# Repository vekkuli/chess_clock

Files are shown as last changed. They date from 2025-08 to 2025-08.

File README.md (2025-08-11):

# Chess Clock :clock1:

Clip

This repo contains design and fabrication files for my DIY chess clock project. The main components in the design are

    Two 4-digit red 7-segment displays
    MAX7219 display driver
    Pro Micro microcontroller board
    3D printed enclosure and other parts
    5 V power supply (e.g. PowerBoost 500C and LiPoly battery)
    Cut-to-shape acrylic window and tint film

## PCB

The KiCad project can be found in [chess_clock_pcb](chess_clock_pcb) folder. The [fabrication files](chess_clock_pcb/fabrication) are also included and can be used to order the PCBs directly. The fabrication files were produced according to JLCPCB requirements. Black solder mask is recommended.

All the components are through-hole. Happy soldering! Just don't make the same mistake I did the first time and forget which side each component is supposed to be on :grin:. See the correct placement here:

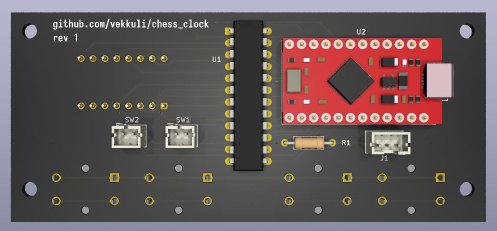
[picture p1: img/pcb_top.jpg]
PCB Top
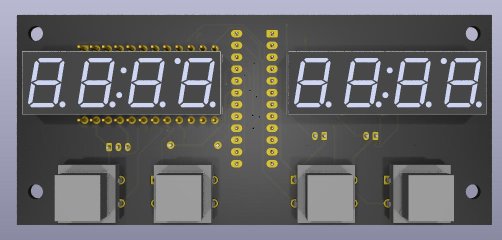
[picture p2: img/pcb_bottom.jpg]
PCB Bottom
 

*Note that the SW2 JST connector is not actually required. I put it there just in case but the current FW does not use it.*

## 3D printed parts

I used black PLA and white PETG. The main body was printed the display/button side facing down and using organic supports (PrusaSlicer). The following mesh files can be found in the [3d_print folder](3d_print):

    3d_print/bottom.3mf
    3d_print/bushing.3mf
    3d_print/button_type1.3mf
    3d_print/button_type1_fill.3mf
    3d_print/button_type2.3mf
    3d_print/button_type2_fill.3mf
    3d_print/main_body.3mf
    3d_print/rocking_switch.3mf

*Note that I actually used off-the-shelf plastic bushings that I just happened to have around, but I imagine 3D printed ones will work just as well.*

## Acrylic window

The acrylic window cut shape can be found in [3d_print/acrylic_cut.dxf](3d_print/acrylic_cut.dxf). 2 mm acrylic can be easily cut using for example a CO2 laser cutter.

The 5 % tint film (e.g. car window tint) is needed to get good contrast from the display.

## Bill of materials

Full (I hope) bill of materials below. Most parts can be sourced from DigiKey.

| Quantity  | Item | Info/part number/digikey |
|---|---|---|
| 2 | 4-digit CC 7-segment display  | TDCR1060M-ND |
| 1 | Display driver | MAX7219CNG-ND |
| 1 | USB-C port for 5 V input | 2057-USB-C20-S-VT-CS15-WP-BK-ND |
| 1 | 10k 1/4W resistor | Affects LED brightness |
| 1 | JST PH 2-pos connector | B2B-PH-K-S |
| 1 | JST PH 3-pos connector | B3B-PH-K-S |
| 1 | Arduino Pro Micro board | Microcontroller board |
| 4 | Tactile switches | SW414-ND |
| 1 | Omron limit switch | SS-5GL13 |
| 1 | PowerBoost 500C | 5V supply and LiPoly charger |
| 1 | LiPoly battery | e.g. 3.7 V/2500 mAh |
| 1 | M2.5 screws and nuts | |
| 1 | M3 screws and nuts | |
| 1 | M4x40 socket head screw | Cut to about 36 mm (or use M4x35) |
| 1 | M4 nyloc nut | |
| 1 | Acrylic window (2 mm) | Laser cut to shape |
| 1 | 5 % dark tint film | Greatly improves display contrast |
| 2 | (optional) O-ring | To soften the button press |

## Pro Micro brownout fix :exclamation:

I don't know how they managed to mess this up :angry: but Pro Micro has a design flaw that causes it to brown out when started by applying power directly via either USB or VCC pin, i.e., not using the regulator on the board. One way to fix this, and what I did, is to remove the regulator IC. While at it, I decided to remove the tantalum capacitors as well.

## Images

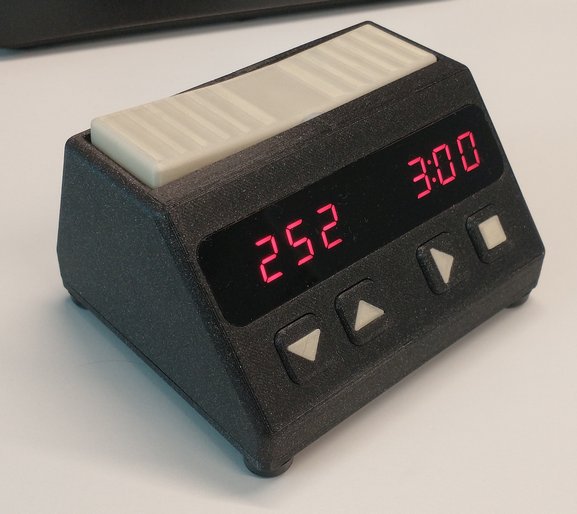
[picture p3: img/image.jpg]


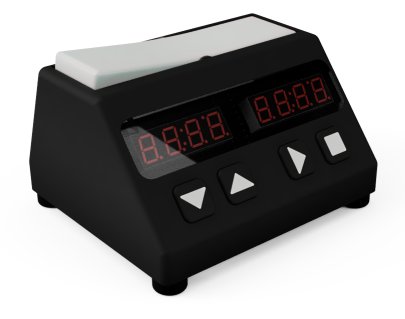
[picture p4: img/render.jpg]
Render


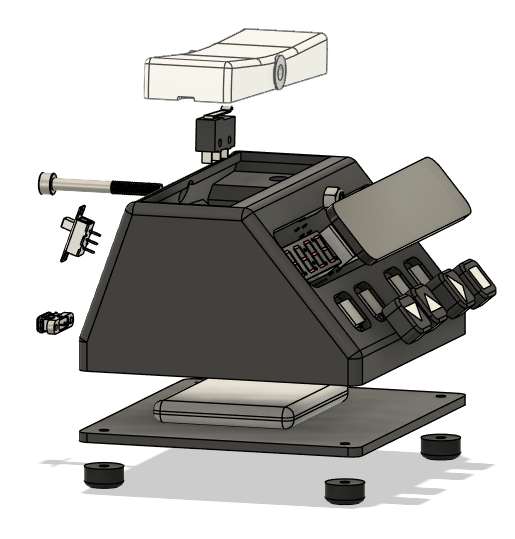
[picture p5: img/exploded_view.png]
Exploded View


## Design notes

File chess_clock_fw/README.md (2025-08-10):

# chess_clock firmware

The script.bat can be used to recover the Pro Micro bootloader in case of crashing program.

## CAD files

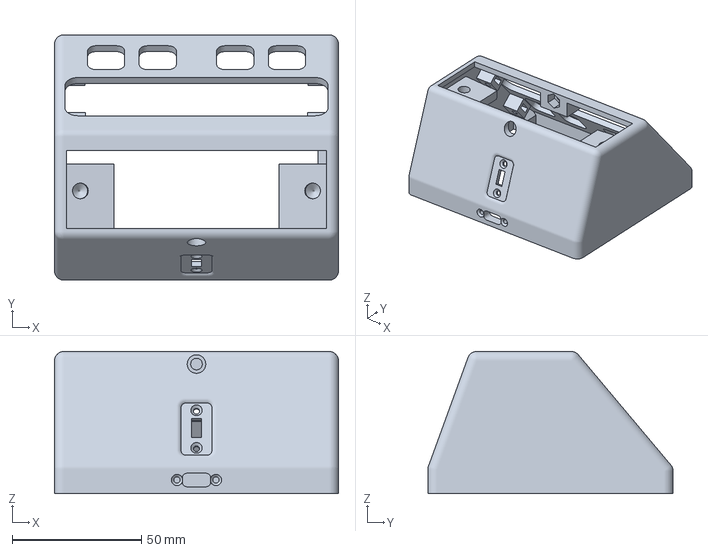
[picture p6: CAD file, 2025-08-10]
3d_print/main_body.3mf
110.0 x 95.0 x 55.0 mm

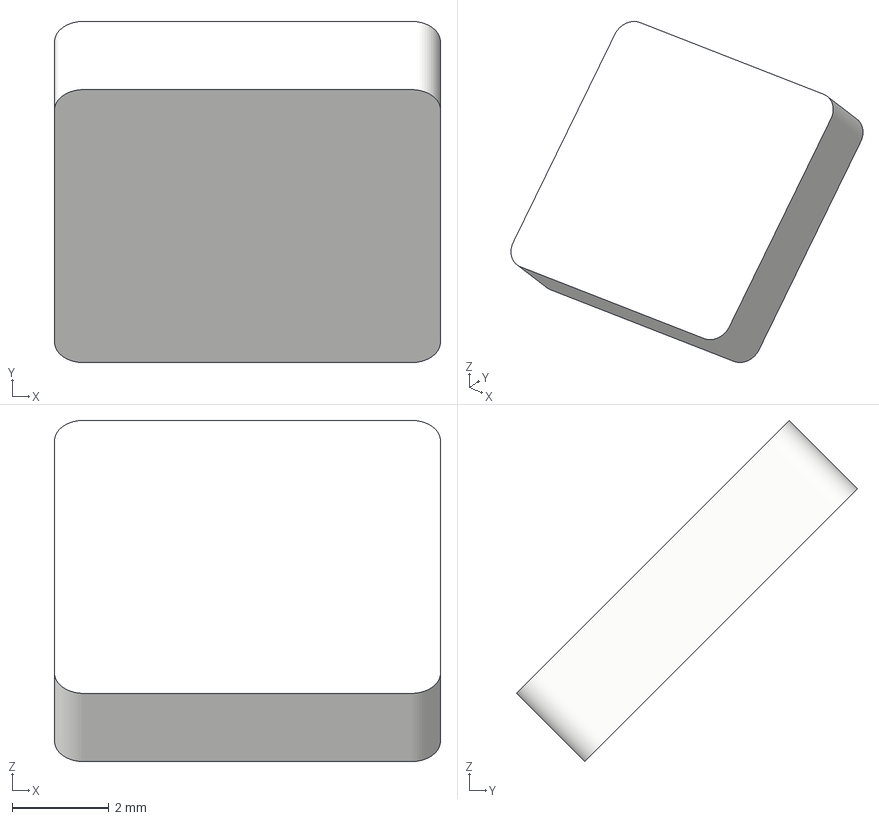
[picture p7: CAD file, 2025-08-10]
3d_print/button_type2_fill.3mf
8.00 x 7.07 x 7.07 mm

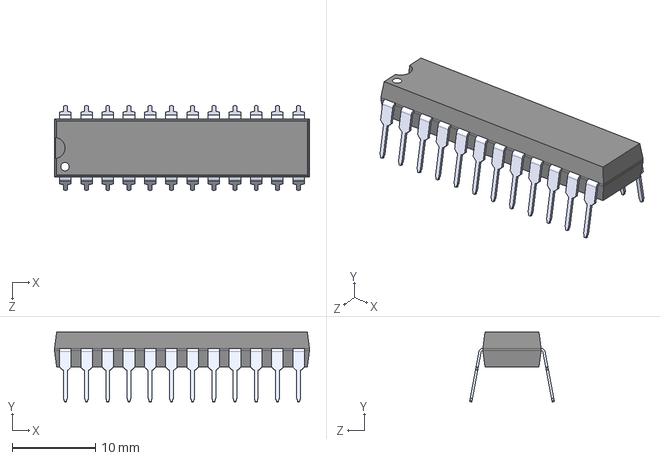
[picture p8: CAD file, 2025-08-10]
chess_clock_pcb/assets/MAX7219CNG.step
30.5 x 8.38 x 10.2 mm

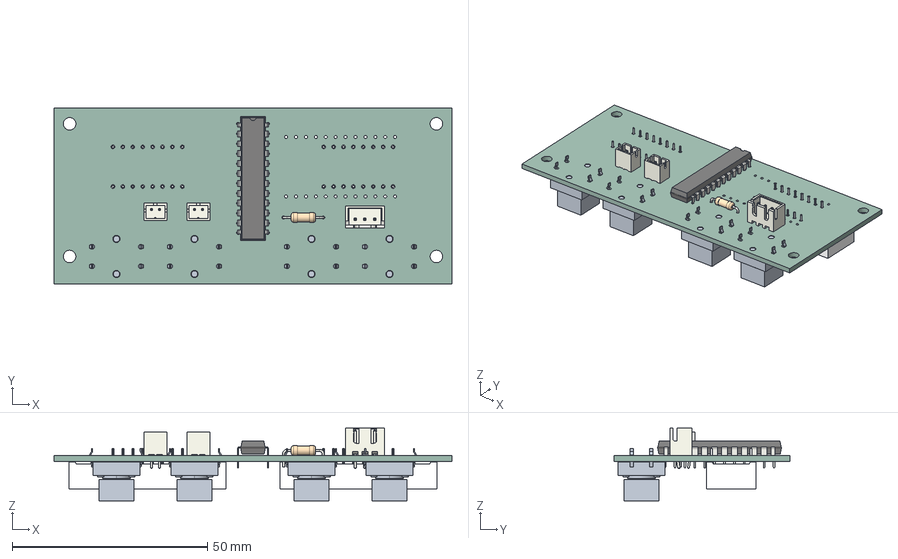
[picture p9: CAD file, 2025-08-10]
chess_clock_pcb/chess_clock_pcb.step
102.0 x 45.0 x 18.7 mm
R_Axial_DIN0207_L6.3mm_D2.5mm_P10.16mm_Horizontal
JST_PH_B2B-PH-K_1x02_P2.00mm_Vertical x 2
DIP-24_W7.62mm
JST_XH_B3B-XH-A_1x03_P2.50mm_Vertical
B3F_4050_BASE x 4
B32_1200 x 4
B3F_4050_BUTTON x 4
TDCR1060M x 2
chess_clock_pcb_PCB

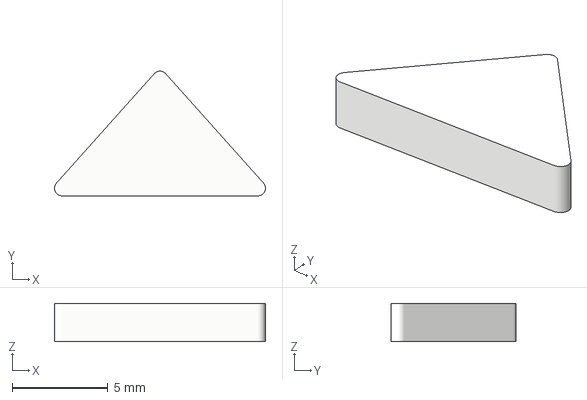
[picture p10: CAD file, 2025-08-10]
3d_print/button_type1_fill.3mf
11.0 x 6.51 x 2.00 mm

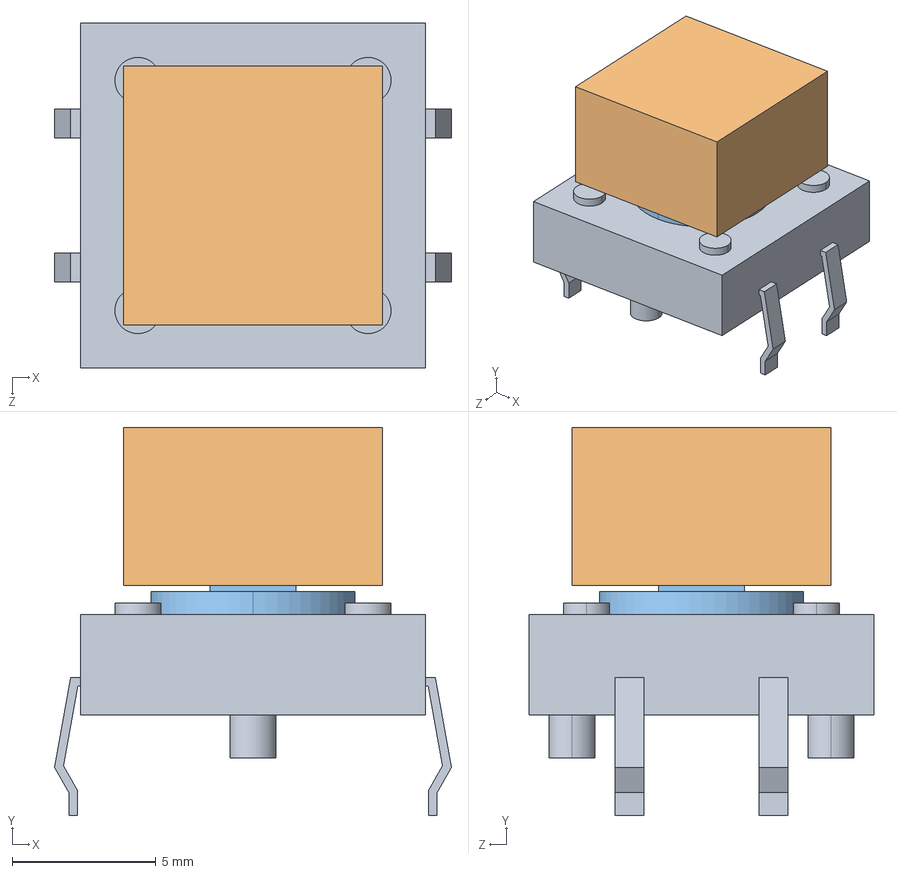
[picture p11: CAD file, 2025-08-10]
chess_clock_pcb/assets/B3F-4050.step
13.8 x 13.5 x 12.0 mm
B3F_4050_BASE
B32_1200
B3F_4050_BUTTON

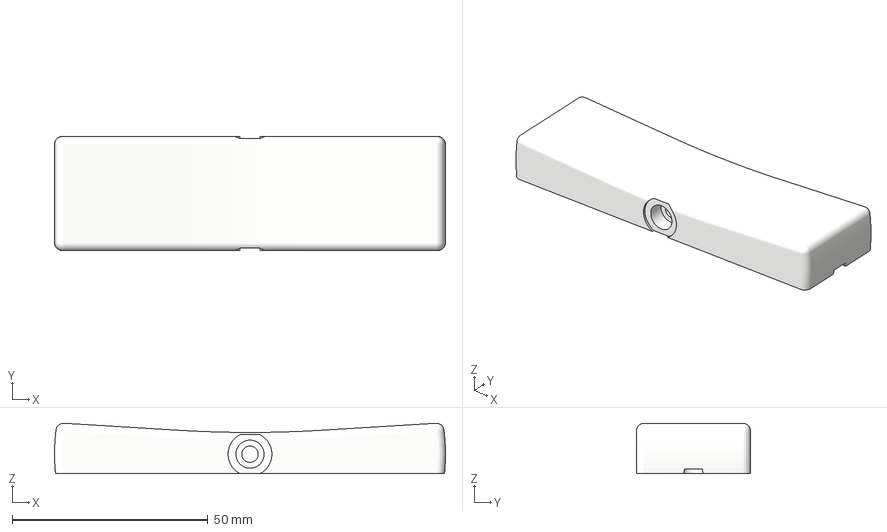
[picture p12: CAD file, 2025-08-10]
3d_print/rocking_switch.3mf
100.0 x 29.2 x 12.9 mm

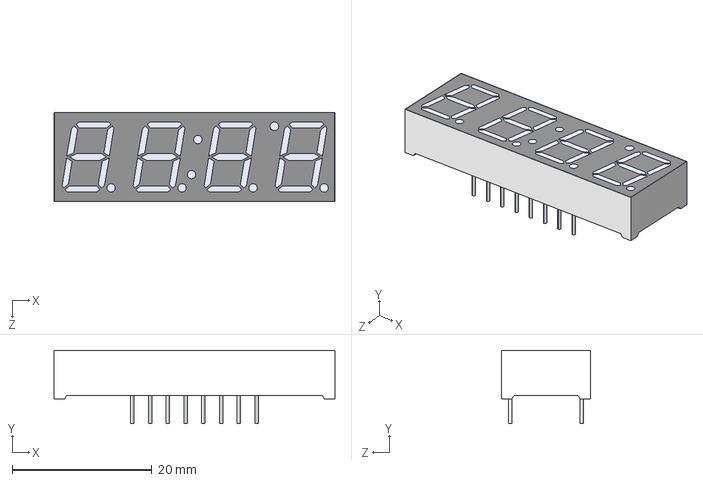
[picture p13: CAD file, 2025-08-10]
chess_clock_pcb/assets/TDCR1060M.step
40.2 x 10.5 x 12.8 mm

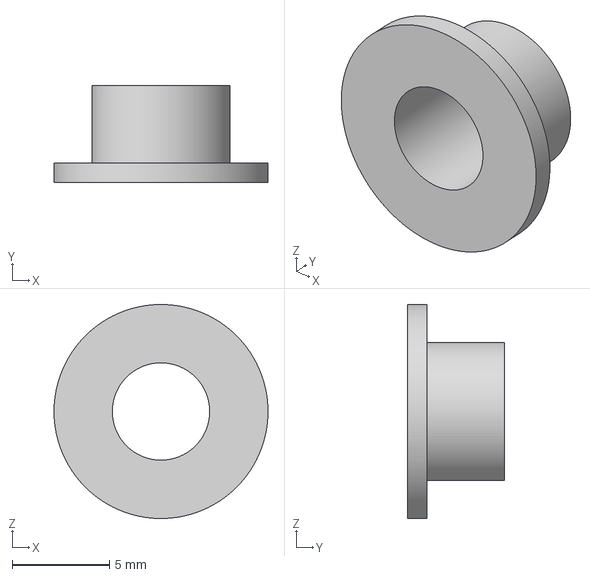
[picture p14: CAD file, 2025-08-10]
3d_print/bushing.3mf
11.0 x 5.00 x 11.0 mm

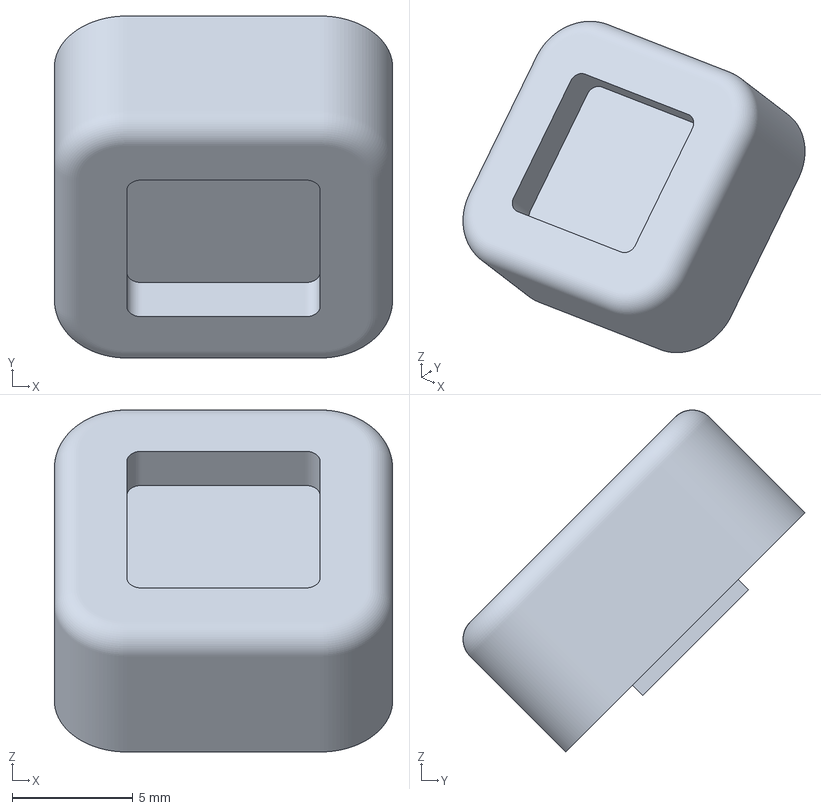
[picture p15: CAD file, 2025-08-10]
3d_print/button_type2.3mf
14.0 x 14.2 x 14.2 mm

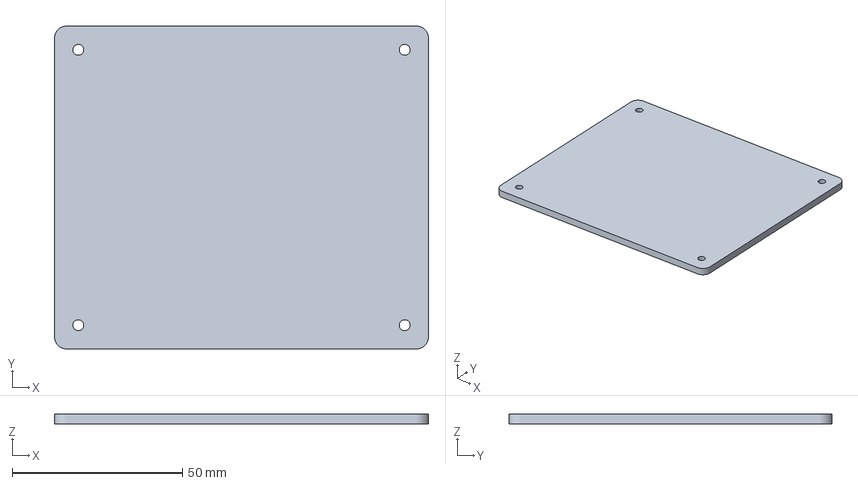
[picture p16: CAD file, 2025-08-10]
3d_print/bottom.3mf
110.0 x 95.0 x 3.00 mm

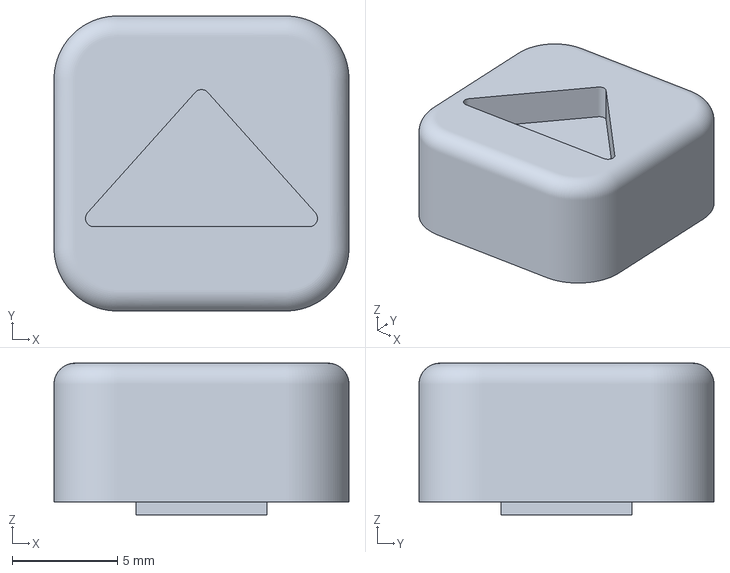
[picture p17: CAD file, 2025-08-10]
3d_print/button_type1.3mf
14.0 x 14.0 x 7.20 mm

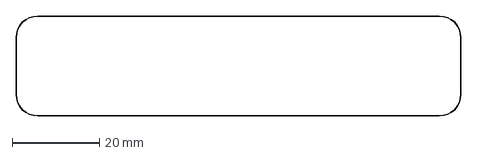
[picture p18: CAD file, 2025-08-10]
3d_print/acrylic_cut.dxf
101.8 x 22.8 mm

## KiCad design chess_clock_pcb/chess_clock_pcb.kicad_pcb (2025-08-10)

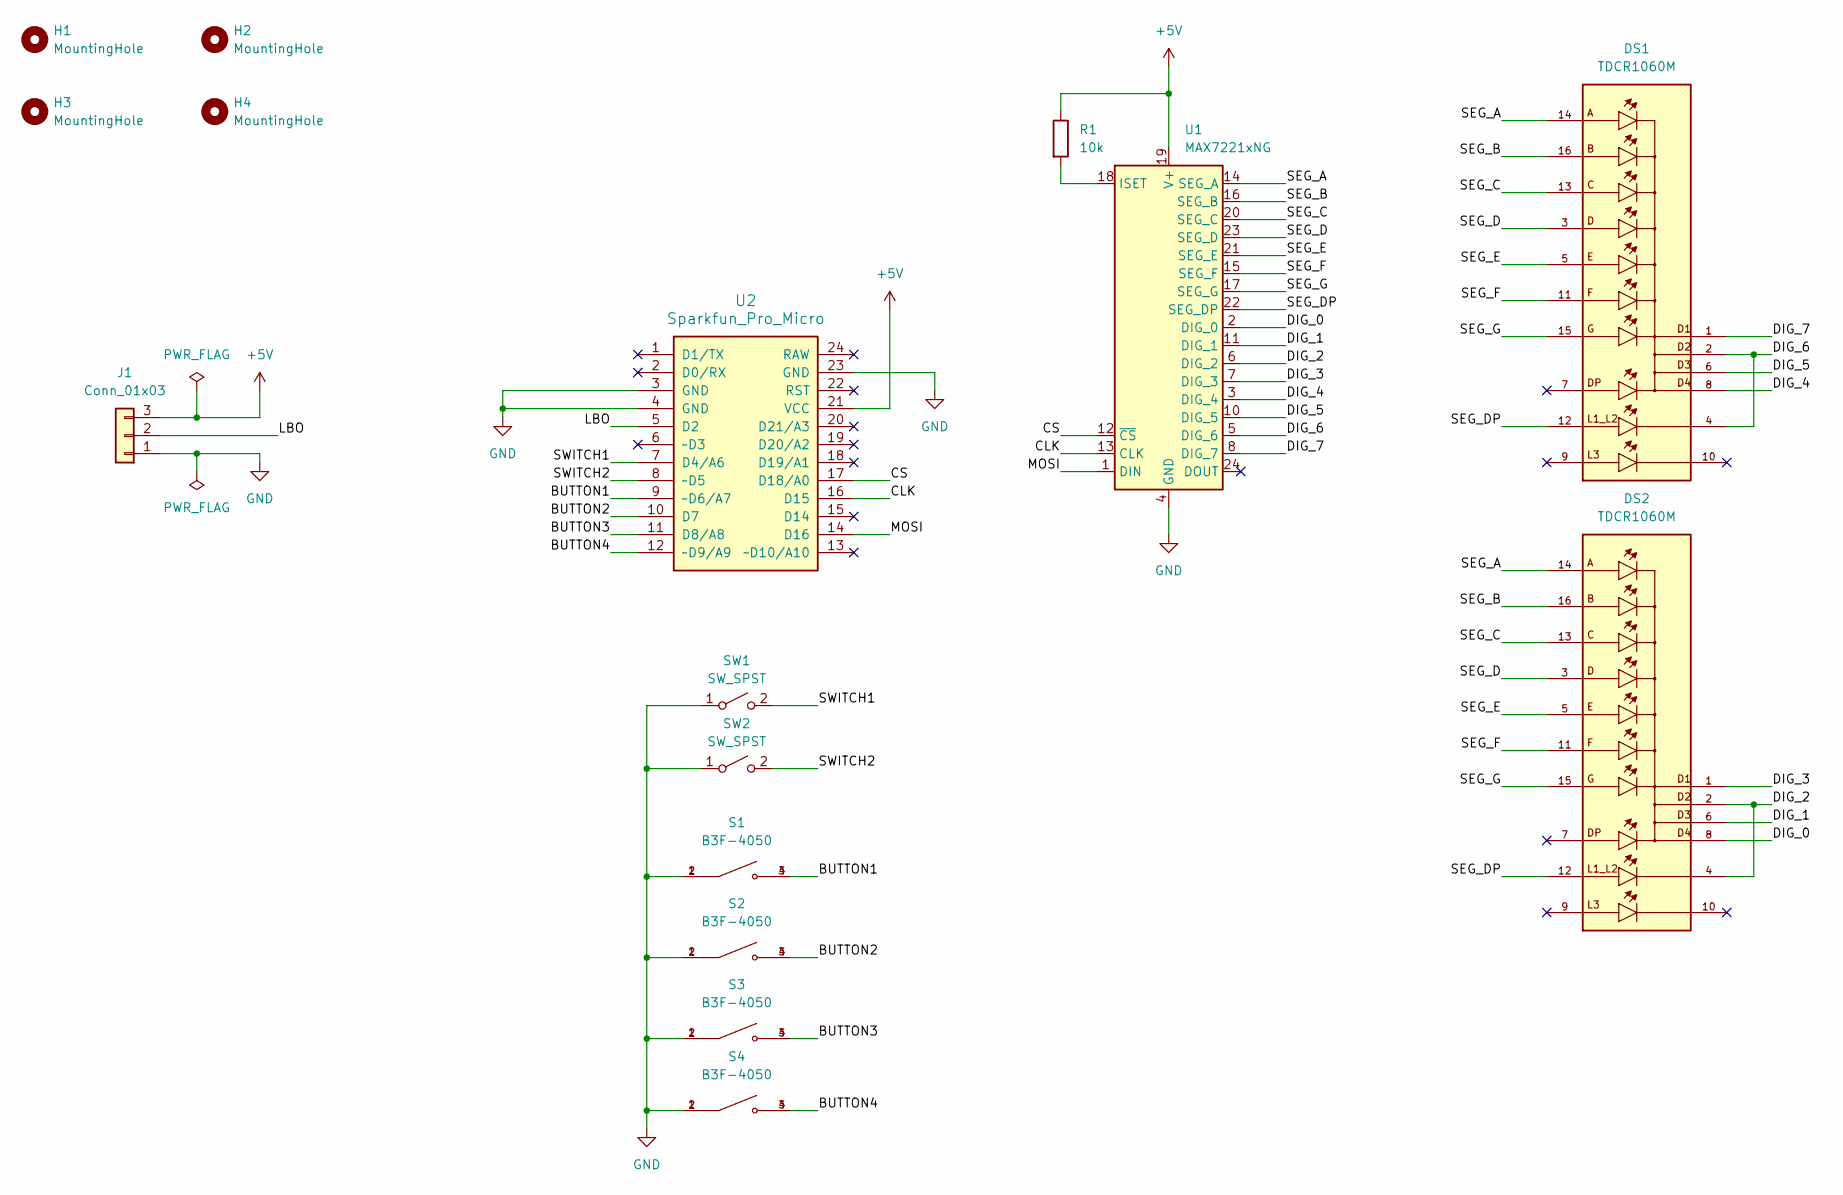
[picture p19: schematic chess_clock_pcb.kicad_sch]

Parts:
DS1, DS2: TDCR1060M; DISPLAY_TDCR1060M; PARTREV 1.7
H1, H2, H3, H4: MountingHole; MountingHole_3.2mm_M3
J1: Conn_01x03; JST_PH_B3B-PH-K_1x03_P2.00mm_Vertical
R1: 10k; R_Axial_DIN0207_L6.3mm_D2.5mm_P10.16mm_Horizontal
S1, S2, S3, S4: B3F-4050; SW_B3F-4050; Digi-Key_Part_Number SW414-ND
SW1, SW2: SW_SPST; JST_PH_B2B-PH-K_1x02_P2.00mm_Vertical
U1: MAX7221xNG; DIP-24_W7.62mm_LongPads
U2: Sparkfun_Pro_Micro

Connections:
+5V: J1.3, R1.1, U1.19 (V+), U2.21 (VCC)
/BUTTON1: S1.3, S1.4, U2.9 (~D6/A7)
/BUTTON2: S2.3, S2.4, U2.10 (D7)
/BUTTON3: S3.3, S3.4, U2.11 (D8/A8)
/BUTTON4: S4.3, S4.4, U2.12 (~D9/A9)
/CLK: U1.13 (CLK), U2.16 (D15)
/CS: U1.12 (~CS), U2.17 (D18/A0)
/DIG_0: DS2.8, U1.2 (DIG_0)
/DIG_1: DS2.6, U1.11 (DIG_1)
/DIG_2: DS2.2, DS2.4, U1.6 (DIG_2)
/DIG_3: DS2.1, U1.7 (DIG_3)
/DIG_4: DS1.8, U1.3 (DIG_4)
/DIG_5: DS1.6, U1.10 (DIG_5)
/DIG_6: DS1.2, DS1.4, U1.5 (DIG_6)
/DIG_7: DS1.1, U1.8 (DIG_7)
/LBO: J1.2, U2.5 (D2)
/MOSI: U1.1 (DIN), U2.14 (D16)
/SEG_A: DS1.14, DS2.14, U1.14 (SEG_A)
/SEG_B: DS1.16, DS2.16, U1.16 (SEG_B)
/SEG_C: DS1.13, DS2.13, U1.20 (SEG_C)
/SEG_D: DS1.3, DS2.3, U1.23 (SEG_D)
/SEG_DP: DS1.12, DS2.12, U1.22 (SEG_DP)
/SEG_E: DS1.5, DS2.5, U1.21 (SEG_E)
/SEG_F: DS1.11, DS2.11, U1.15 (SEG_F)
/SEG_G: DS1.15, DS2.15, U1.17 (SEG_G)
/SWITCH1: SW1.2 (B), U2.7 (D4/A6)
/SWITCH2: SW2.2 (B), U2.8 (~D5)
GND: J1.1, S1.1, S1.2, S2.1, S2.2, S3.1, S3.2, S4.1, S4.2, SW1.1 (A), SW2.1 (A), U1.4 (GND), U1.9 (GND), U2.3 (GND), U2.4 (GND), U2.23 (GND)
unnamed: R1.2, U1.18 (ISET)

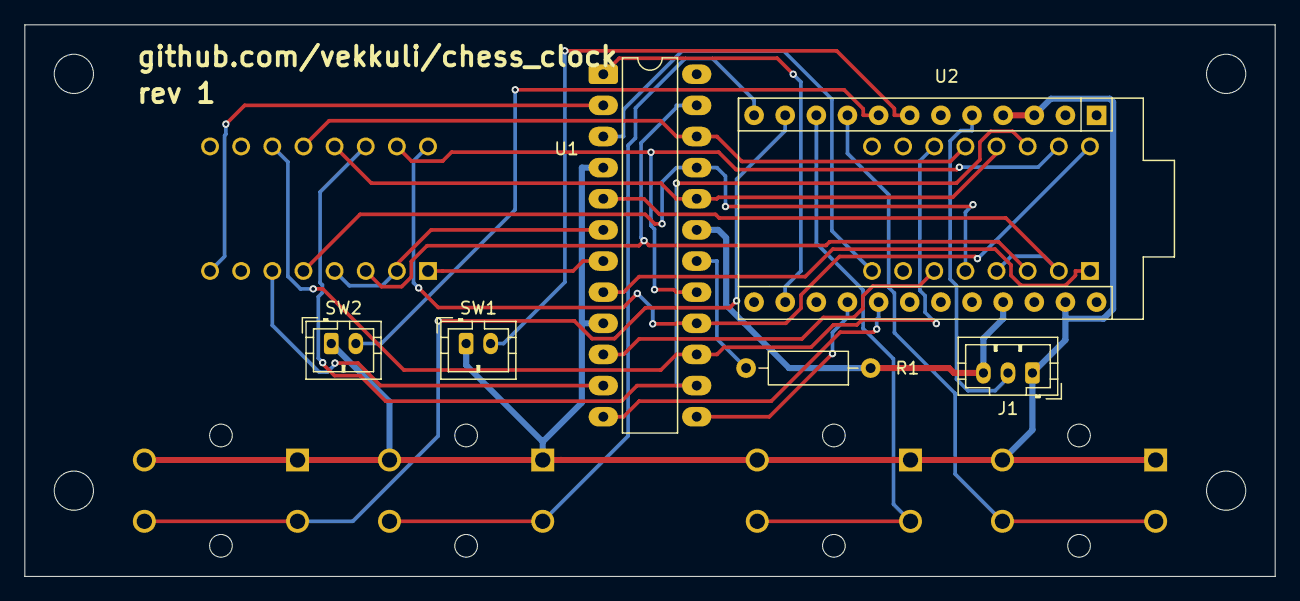
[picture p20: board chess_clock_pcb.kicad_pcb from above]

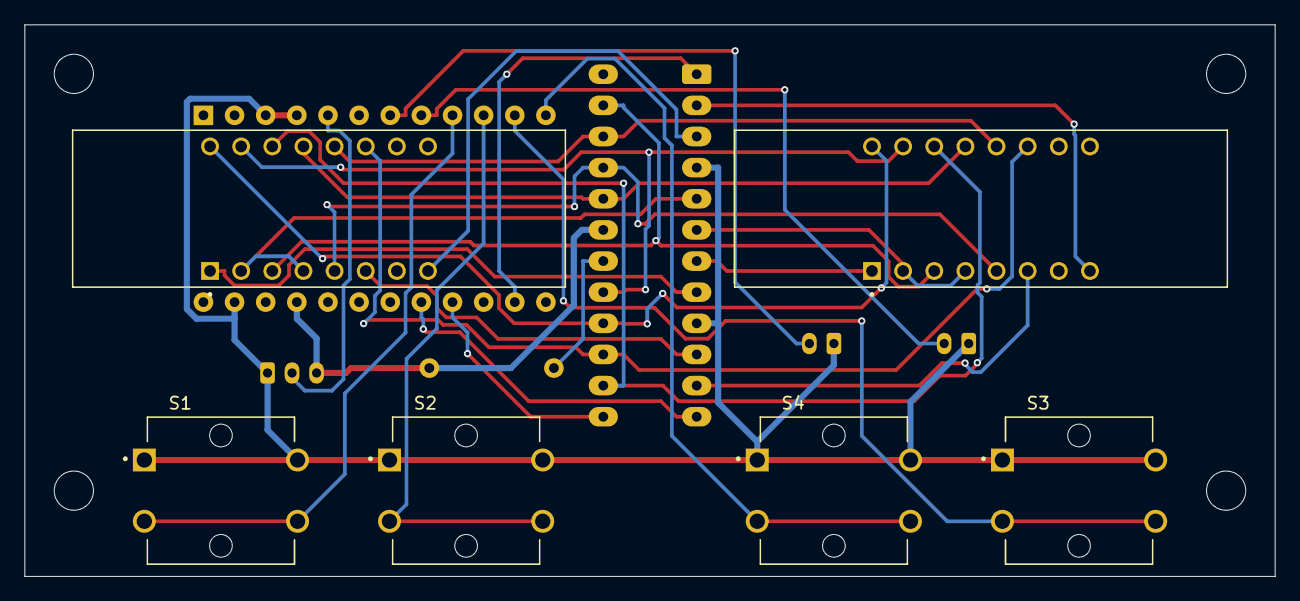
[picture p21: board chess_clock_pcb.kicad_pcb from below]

Board: 2 copper layers, 102.0 x 45.0 mm, 16 parts (6 on the bottom side), 29 nets.

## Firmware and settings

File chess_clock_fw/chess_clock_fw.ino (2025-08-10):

#define MAX7219_CLK_PIN 15
#define MAX7219_DIN_PIN 16
#define MAX7219_CS_PIN 18

#define DOWN_BUTTON_PIN 6
#define UP_BUTTON_PIN 7
#define STOP_BUTTON_PIN 8
#define PLAY_BUTTON_PIN 9

#define TURN_SWITCH_PIN 4

#define LBO_PIN 2

#include "EasyButton.h"
#include "serial_debug.h"
#include "system.h"
#include "display.h"
#include "game.h"
#include "timecontrol.h"

Display System::display = Display(MAX7219_CLK_PIN, MAX7219_DIN_PIN, MAX7219_CS_PIN);
Game System::game;

FSM_INITIAL_STATE(System, Startup)

//
// Buttons (all 35 ms debounce time, pulled up, active low)
EasyButton playButton(PLAY_BUTTON_PIN);
EasyButton stopButton(STOP_BUTTON_PIN);
EasyButton upButton(UP_BUTTON_PIN);
EasyButton downButton(DOWN_BUTTON_PIN);
EasyButton turnSwitch(TURN_SWITCH_PIN, 35U, true, false);

void onPlayButtonPressed() { System::dispatch(PlayButtonPressed()); }
void onStopButtonPressed() { System::dispatch(StopButtonPressed()); }
void onStopButtonHeld() { System::dispatch(StopButtonHeld()); }
void onUpButtonPressed() { System::dispatch(UpButtonPressed()); }
void onDownButtonPressed() { System::dispatch(DownButtonPressed()); }

void setup()
{
    System::start(); // Start the state machine
    System::display.begin();

    pinMode(LBO_PIN, INPUT);

    playButton.begin();
    playButton.onPressed(onPlayButtonPressed);

    stopButton.begin();
    stopButton.onPressed(onStopButtonPressed);
    stopButton.onPressedFor(1000, onStopButtonHeld);

    upButton.begin();
    upButton.onPressed(onUpButtonPressed);

    downButton.begin();
    downButton.onPressed(onDownButtonPressed);

    turnSwitch.begin();
}

void loop()
{
    System::display.setLowBatteryState(digitalRead(LBO_PIN) == LOW);
    playButton.read();
    stopButton.read();
    upButton.read();
    downButton.read();
    if (System::game.setTurnSwitchState(turnSwitch.read()))
        System::display.flash();
    System::current_state_ptr->tick();
    System::display.updateDisplay();
}

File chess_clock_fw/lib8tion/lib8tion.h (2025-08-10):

#pragma once

/*

 Fast, efficient 8-bit math functions specifically
 designed for high-performance LED programming.

 Because of the AVR(Arduino) and ARM assembly language
 implementations provided, using these functions often
 results in smaller and faster code than the equivalent
 program using plain "C" arithmetic and logic.


 Included are:


 - Saturating unsigned 8-bit add and subtract.
   Instead of wrapping around if an overflow occurs,
   these routines just 'clamp' the output at a maxumum
   of 255, or a minimum of 0.  Useful for adding pixel
   values.  E.g., qadd8( 200, 100) = 255.

     qadd8( i, j) == MIN( (i + j), 0xFF )
     qsub8( i, j) == MAX( (i - j), 0 )

 - Saturating signed 8-bit ("7-bit") add.
     qadd7( i, j) == MAX( MIN( (i + j), 0x7F), -0x80)


 - Scaling (down) of unsigned 8- and 16- bit values.
   Scaledown value is specified in 1/256ths.
     scale8( i, sc) == (i * sc) / 256
     scale16by8( i, sc) == (i * sc) / 256

   Example: scaling a 0-255 value down into a
   range from 0-99:
     downscaled = scale8( originalnumber, 100);

   A special version of scale8 is provided for scaling
   LED brightness values, to make sure that they don't
   accidentally scale down to total black at low
   dimming levels, since that would look wrong:
     scale8_video( i, sc) = ((i * sc) / 256) +? 1

   Example: reducing an LED brightness by a
   dimming factor:
     new_bright = scale8_video( orig_bright, dimming);


 - Fast 8- and 16- bit unsigned random numbers.
   Significantly faster than Arduino random(), but
   also somewhat less random.  You can add entropy.
     random8()       == random from 0..255
     random8( n)     == random from 0..(N-1)
     random8( n, m)  == random from N..(M-1)

     random16()      == random from 0..65535
     random16( n)    == random from 0..(N-1)
     random16( n, m) == random from N..(M-1)

     random16_set_seed( k)    ==  seed = k
     random16_add_entropy( k) ==  seed += k


 - Absolute value of a signed 8-bit value.
     abs8( i)     == abs( i)


 - 8-bit math operations which return 8-bit values.
   These are provided mostly for completeness,
   not particularly for performance.
     mul8( i, j)  == (i * j) & 0xFF
     add8( i, j)  == (i + j) & 0xFF
     sub8( i, j)  == (i - j) & 0xFF


 - Fast 16-bit approximations of sin and cos.
   Input angle is a uint16_t from 0-65535.
   Output is a signed int16_t from -32767 to 32767.
      sin16( x)  == sin( (x/32768.0) * pi) * 32767
      cos16( x)  == cos( (x/32768.0) * pi) * 32767
   Accurate to more than 99% in all cases.

 - Fast 8-bit approximations of sin and cos.
   Input angle is a uint8_t from 0-255.
   Output is an UNsigned uint8_t from 0 to 255.
       sin8( x)  == (sin( (x/128.0) * pi) * 128) + 128
       cos8( x)  == (cos( (x/128.0) * pi) * 128) + 128
   Accurate to within about 2%.


 - Fast 8-bit "easing in/out" function.
     ease8InOutCubic(x) == 3(x^2) - 2(x^3)
     ease8InOutApprox(x) ==
       faster, rougher, approximation of cubic easing
     ease8InOutQuad(x) == quadratic (vs cubic) easing

 - Cubic, Quadratic, and Triangle wave functions.
   Input is a uint8_t representing phase withing the wave,
     similar to how sin8 takes an angle 'theta'.
   Output is a uint8_t representing the amplitude of
     the wave at that point.
       cubicwave8( x)
       quadwave8( x)
       triwave8( x)

 - Square root for 16-bit integers.  About three times
   faster and five times smaller than Arduino's built-in
   generic 32-bit sqrt routine.
     sqrt16( uint16_t x ) == sqrt( x)

 - Dimming and brightening functions for 8-bit
   light values.
     dim8_video( x)  == scale8_video( x, x)
     dim8_raw( x)    == scale8( x, x)
     dim8_lin( x)    == (x<128) ? ((x+1)/2) : scale8(x,x)
     brighten8_video( x) == 255 - dim8_video( 255 - x)
     brighten8_raw( x) == 255 - dim8_raw( 255 - x)
     brighten8_lin( x) == 255 - dim8_lin( 255 - x)
   The dimming functions in particular are suitable
   for making LED light output appear more 'linear'.


 - Linear interpolation between two values, with the
   fraction between them expressed as an 8- or 16-bit
   fixed point fraction (fract8 or fract16).
     lerp8by8(   fromU8, toU8, fract8 )
     lerp16by8(  fromU16, toU16, fract8 )
     lerp15by8(  fromS16, toS16, fract8 )
       == from + (( to - from ) * fract8) / 256)
     lerp16by16( fromU16, toU16, fract16 )
       == from + (( to - from ) * fract16) / 65536)
     map8( in, rangeStart, rangeEnd)
       == map( in, 0, 255, rangeStart, rangeEnd);

 - Optimized memmove, memcpy, and memset, that are
   faster than standard avr-libc 1.8.
      memmove8( dest, src,  bytecount)
      memcpy8(  dest, src,  bytecount)
      memset8(  buf, value, bytecount)

 - Beat generators which return sine or sawtooth
   waves in a specified number of Beats Per Minute.
   Sine wave beat generators can specify a low and
   high range for the output.  Sawtooth wave beat
   generators always range 0-255 or 0-65535.
     beatsin8( BPM, low8, high8)
         = (sine(beatphase) * (high8-low8)) + low8
     beatsin16( BPM, low16, high16)
         = (sine(beatphase) * (high16-low16)) + low16
     beatsin88( BPM88, low16, high16)
         = (sine(beatphase) * (high16-low16)) + low16
     beat8( BPM)  = 8-bit repeating sawtooth wave
     beat16( BPM) = 16-bit repeating sawtooth wave
     beat88( BPM88) = 16-bit repeating sawtooth wave
   BPM is beats per minute in either simple form
   e.g. 120, or Q8.8 fixed-point form.
   BPM88 is beats per minute in ONLY Q8.8 fixed-point
   form.

Lib8tion is pronounced like 'libation': lie-BAY-shun

*/



#include <stdint.h>

#define LIB8STATIC __attribute__ ((unused)) static inline
#define LIB8STATIC_ALWAYS_INLINE __attribute__ ((always_inline)) static inline

#if !defined(__AVR__)
#include <string.h>
// for memmove, memcpy, and memset if not defined here
#endif // end of !defined(__AVR__)

#if defined(__arm__)

#if defined(FASTLED_TEENSY3)
// Can use Cortex M4 DSP instructions
#define QADD8_C 0
#define QADD7_C 0
#define QADD8_ARM_DSP_ASM 1
#define QADD7_ARM_DSP_ASM 1
#else
// Generic ARM
#define QADD8_C 1
#define QADD7_C 1
#endif // end of defined(FASTLED_TEENSY3)

#define QSUB8_C 1
#define SCALE8_C 1
#define SCALE16BY8_C 1
#define SCALE16_C 1
#define ABS8_C 1
#define MUL8_C 1
#define QMUL8_C 1
#define ADD8_C 1
#define SUB8_C 1
#define EASE8_C 1
#define AVG8_C 1
#define AVG8R_C 1
#define AVG7_C 1
#define AVG16_C 1
#define AVG16R_C 1
#define AVG15_C 1
#define BLEND8_C 1

// end of #if defined(__arm__)

#elif defined(ARDUINO_ARCH_APOLLO3)

// Default to using the standard C functions for now
#define QADD8_C 1
#define QADD7_C 1
#define QSUB8_C 1
#define SCALE8_C 1
#define SCALE16BY8_C 1
#define SCALE16_C 1
#define ABS8_C 1
#define MUL8_C 1
#define QMUL8_C 1
#define ADD8_C 1
#define SUB8_C 1
#define EASE8_C 1
#define AVG8_C 1
#define AVG8R_C 1
#define AVG7_C 1
#define AVG16_C 1
#define AVG16R_C 1
#define AVG15_C 1
#define BLEND8_C 1
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

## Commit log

2025-08-10 Committed public version of the repo.
    [B3F-4050.step, MAX7219CNG.step, TDCR1060M.step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]
2025-08-11 Added a GIF clip of the device in action and a photo
